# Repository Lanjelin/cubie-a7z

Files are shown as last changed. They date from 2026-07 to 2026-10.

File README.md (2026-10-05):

# Cubie A7Z setup notes

This repository is a working notebook for a Radxa Cubie A7Z running Armbian. It collects the bits that made the board useful: first-boot configuration, Wi-Fi fallback setup, fan control, e-paper display experiments, a status display script, and printable enclosure files.

It is intentionally practical rather than polished. Some directories are hardware bring-up notes, some are deployable scripts, and some are snapshots of a known-good local environment.

<p align="center">
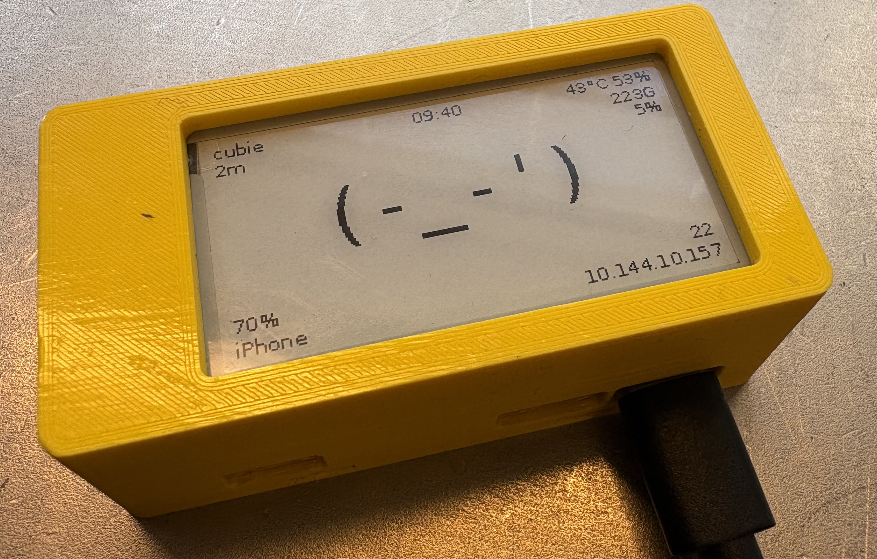
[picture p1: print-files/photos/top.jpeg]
Cubie A7Z enclosure top view
  
</p>

<p align="center">
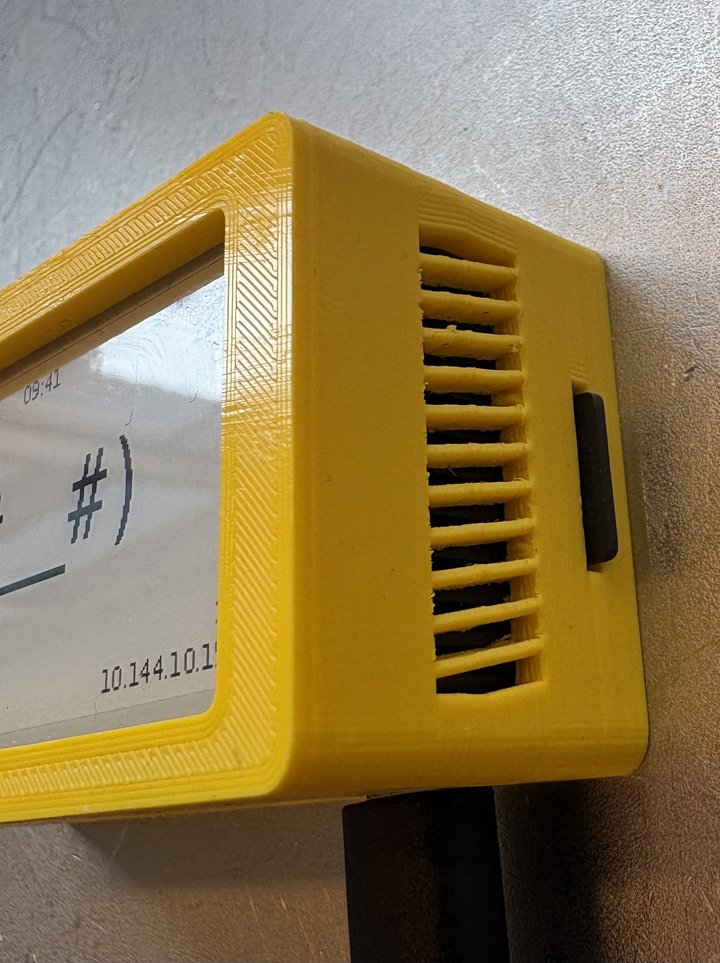
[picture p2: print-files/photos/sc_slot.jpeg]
Cubie A7Z enclosure SD card slot detail
  
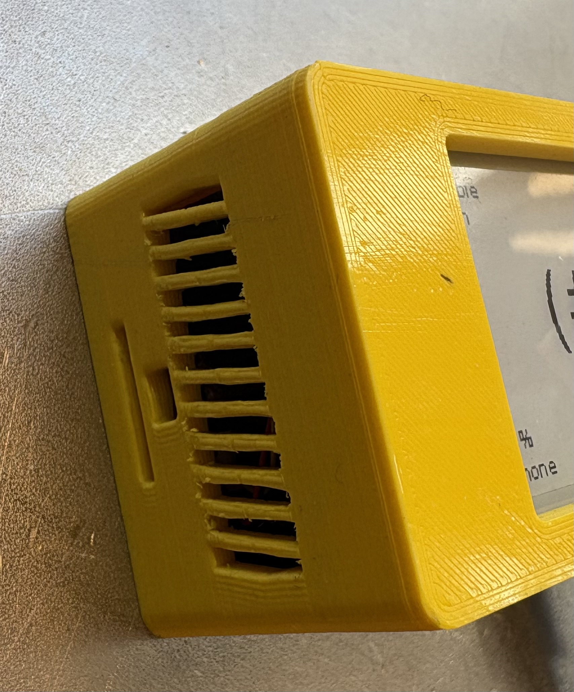
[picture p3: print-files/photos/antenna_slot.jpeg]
Cubie A7Z enclosure antenna slot detail
  
</p>

## Quick start order

This is the intended path through the repo when bringing up a fresh Cubie A7Z:

1. Flash an Armbian image for the Cubie A7Z.
2. Optionally prepare first boot with `armbian/.not_logged_in_yet.example`.
3. For the current Waveshare display, install the `cubie-header-io-power` overlay and verify `/dev/spidev1.0`; the current base DTB already enables SPI1.
4. Configure Wi-Fi and the fallback AP from `wifi/`.
5. Install `fan/` if using the vendor stock cooling/fan.
6. Test the e-paper status display with `screen-time/screen-time.py --once`.
7. Install `screen-time/screen-time.service` for boot startup.
8. Print or modify the enclosure from `print-files/`.

## Printable enclosure

The Cubie A7Z enclosure files live in [`print-files/`](print-files/). That folder includes editable CAD, STEP export, print-ready 3MF files, CAD screenshots, and photos of the printed result. The enclosure covers the stock vendor cooling/fan setup and includes ventilation holes plus cutouts for the camera, antenna, SD card, HDMI, and USB.

## Repository map

| Path | What it contains |
| --- | --- |
| `armbian/` | Armbian-specific setup notes. `armbian/.not_logged_in_yet.example` is a first-boot autoconfig template copied from the Armbian documentation. |
| `fan/` | A simple PWM fan daemon for the Cubie A7Z plus a systemd unit. The daemon reads thermal zones, ignores `skin_zone`, and writes `/sys/class/hwmon/hwmon1/pwm1` using a small temperature curve. |
| `wifi/` | NetworkManager/netplan notes for normal Wi-Fi plus a fallback access point. The timer/service waits after boot and starts the `cubie-ap` connection if `wlan0` never gets an IPv4 address or active Wi-Fi client connection. |
| `inky-fix/` | The older Pimoroni Inky pHAT bring-up path. Includes the Cubie A7Z patch, SPI1 overlay source/compiled DTBO, and minimal examples for the SSD1608 pHAT driver. |
| `waveshare-2in13-v4/` | Waveshare 2.13 inch e-Paper HAT+ V4 bring-up. Includes a trimmed vendored `waveshare_epd/` driver copy, examples, and the `cubie-header-io-power.dts` source. |
| `screen-time/` | The current Waveshare-based status display project. It bundles the patched Waveshare driver, header power overlay source, minimal Python requirements, and `screen-time.py`, which renders a landscape status screen and uses partial refreshes with periodic full refreshes. |
| `print-files/` | Printable Cubie A7Z enclosure files: editable CAD, STEP export, print-ready 3MF files, screenshots, photos, and feature notes in `print-files/README.md`. |

## Armbian notes

The board is running Armbian.

- General Armbian documentation: <https://docs.armbian.com/>
- First-boot autoconfig docs: <https://docs.armbian.com/User-Guide_Autoconfig/>
- Local template: [`armbian/.not_logged_in_yet.example`](armbian/.not_logged_in_yet.example)
- Radxa Cubie A7Z Armbian images: <https://github.com/NickAlilovic/build/releases>
- Armbian forum thread for Radxa Cubie A7 / A7Z / Allwinner A733: <https://forum.armbian.com/topic/56130-radxa-cubie-a7aa7z-allwinner-a733/>

Typical flow for first boot:

1. Flash an Armbian image.
2. Mount the flashed image or boot media.
3. Copy `armbian/.not_logged_in_yet.example` to `/root/.not_logged_in_yet` on that mounted filesystem.
4. Replace every placeholder value before booting. Armbian stores these values in plaintext, including Wi-Fi and user/root passwords.
5. Boot the Cubie A7Z and let Armbian consume the file during first boot.

## Current Waveshare header power overlay

The current kernel base DTB already enables SPI1 with native `PD10`–`PD13` pinctrl and one `spidev@0`, exposing `/dev/spidev1.0`. Do not load the old manual-CS SPI overlay for the current Waveshare setup. The necessary recovery is to keep the header I/O-bank power switch enabled.

The confirmed black/white Waveshare 2.13inch V4 HAT mapping is:

| Signal | Header pin | GPIO/controller |
| --- | --- | --- |
| Reset | 11 | `PB1`, `gpiochip0` offset `33` |
| BUSY | 18 | `PJ25`, `gpiochip0` offset `313` |
| DC | 22 | `PL5`, `gpiochip1` offset `5` |
| CS | 24 | `PD10`, native SPI1 chip select owned by the kernel |

Offsets are local to each gpiochip, not BCM numbers. The backend sets `CS_PIN=None`, leaving GPIO CS writes as no-ops; never request `PD10` with gpiod. SPI uses bus `1`, device `0`, mode `0`, `500000` Hz and `no_cs=False`.

`screen-time/cubie-header-io-power.dts` (also preserved in `waveshare-2in13-v4/`) adds only `regulator-boot-on` and `regulator-always-on` to `&reg_dc1sw1`. This enables `VCC33-LCD`/`SWOUT1` power for the PD (SPI1) and PJ (BUSY) banks without changing pinctrl or disabling Wi-Fi. The deployed application in `/opt/screen-time` does not need an overlay source or compiled DTBO at runtime; keep the checked-in source for rebuilding the boot overlay.

From the repository root:

```bash
dtc -@ -I dts -O dtb -o screen-time/cubie-header-io-power.dtbo screen-time/cubie-header-io-power.dts
sudo install -d /boot/overlay-user
sudo install -m 0644 screen-time/cubie-header-io-power.dtbo /boot/overlay-user/cubie-header-io-power.dtbo
sudo nano /boot/armbianEnv.txt
```

Edit the existing `user_overlays` line, removing the obsolete `sun60iw2p1-spi1-spidev-manual-cs` token and adding `cubie-header-io-power`. Preserve any unrelated tokens. With no unrelated overlays:

```ini
user_overlays=cubie-header-io-power
```

Keep Wi-Fi enabled; no Wi-Fi disable overlay is needed. Reboot to apply the boot-time power change:

```bash
sudo reboot
```

After reconnecting, verify the SPI node and follow `screen-time/README.md` for dependencies, a `screen-time.py --once` run, and service installation. A present SPI node alone does not prove that the header banks are powered.

### Apt-upgrade regression and confirmed recovery

The upgraded base DTB omitted the original Radxa board DTS's `regulator-boot-on` for `dc1sw1`. SPI1 remained enabled, and GPIO/pinctrl source was unchanged, but `dc1sw1` was disabled while its parent `DCDC1` still supplied 3.3 V. The resulting unpowered `VCC33-LCD` header banks caused the display failure.

With `cubie-header-io-power` and native CS, the recovery diagnostic showed BUSY rising and a full refresh of `2.283 s`; visible panel updates were confirmed. The deployed status application also completed full and partial refreshes, with a partial-refresh BUSY wait of about `0.60 s`. The installed recovery uses `user_overlays=cubie-header-io-power` and preserves Wi-Fi.

References: [Radxa A7Z schematic v1.11, pages 4 and 7](https://dl.radxa.com/cubie/a7z/docs/hw/radxa_cubie_a7z_schematic_v1.11.pdf) and [original Radxa board DTS](https://github.com/radxa/allwinner-device/blob/device-a733-v1.4.8/configs/cubie_a7z/linux-6.6/board.dts).

### Historical Inky overlay path

`inky-fix/` retains its old `spi1-spidev-manual-cs.dts` and `sun60iw2p1-spi1-spidev-manual-cs.dtbo` for the older Pimoroni bring-up path. Those assets are historical and are not the active Waveshare overlay; do not load them alongside the current native-CS base DTB. They have intentionally been left intact.

## Display work

There are three display-related folders because the setup moved from Inky experiments to the current Waveshare status display.

### `inky-fix/`

Captures the Pimoroni Inky pHAT path. `inky.auto.auto()` did not work on this board because the EEPROM was not visible on the accessible I2C buses, so the working path used the manual SSD1608 pHAT class with Cubie-specific pins.

### `waveshare-2in13-v4/`

Captures the Waveshare 2.13 inch e-Paper HAT+ V4 bring-up. It keeps a local `waveshare_epd/` copy so Cubie pin and SPI fixes can be made without patching a global install. The full upstream Waveshare repository is <https://github.com/waveshareteam/e-Paper>.

### `screen-time/`

The status display application built on the Waveshare V4 setup. It defaults `EPD_PLATFORM=cubie`, imports its bundled `waveshare_epd` driver, renders through Pillow, and supports:

- one-shot test mode with `python3 screen-time.py --once`
- normal loop mode with `python3 screen-time.py`
- custom refresh interval with `python3 screen-time.py --interval 15`

## Wi-Fi fallback access point

`wifi/` contains notes and unit files for making the board recoverable when normal Wi-Fi does not connect.

- `etc_netplan_30-wifis-dhcp.yaml.example` is a netplan Wi-Fi config snapshot.
- `nmcli_network_priority_ap` records NetworkManager commands for connection priorities and the fallback AP.
- `wifi-fallback-ap.sh` waits for normal Wi-Fi, then brings up `cubie-ap` if no IPv4 address or active Wi-Fi client connection exists.
- `wifi-fallback-ap.service` and `wifi-fallback-ap.timer` run that check after boot.

## Fan daemon

`fan/cubie-fand` is a small Python daemon intended to be installed as `/usr/local/sbin/cubie-fand` and run with `fan/cubie-fand.service`.

It sets manual PWM mode, starts at a minimum PWM, samples thermal zones every five seconds, and raises/lowers the fan using hysteresis to avoid rapid speed changes.

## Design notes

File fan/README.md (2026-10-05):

# Cubie A7Z fan daemon

This directory contains a small PWM fan controller for the Cubie A7Z stock cooling/fan setup.

`cubie-fand` reads thermal zones from `/sys/class/thermal`, ignores `skin_zone`, and writes PWM values to the hwmon device whose `name` is `pwmfan`. The `hwmonN` number is discovered at startup, not hard-coded. It uses a small temperature curve plus hysteresis so the fan does not constantly bounce between speeds.

## Files

| File | Purpose |
| --- | --- |
| `cubie-fand` | Python fan control daemon. |
| `cubie-fand.service` | systemd service unit. |
| `cubie-pwm-fan.dts` / `.dtbo` | Restore the fan device and PWM1 channel 9 routing to PJ27 after the kernel upgrade. |

## Kernel-upgrade recovery

The upgraded base DTB omits the original `pwm-fan` device and routes PWM1 channel 9 to PK5 instead of the fan connector's PJ27. The kernel includes `pwm-fan.ko`, but without the device node there is no fan hwmon interface: the old daemon crashes at startup and the status display shows `--%`.

`cubie-pwm-fan.dts` restores PJ27 active/sleep pinctrl and a `pwm-fan` device using PWM1 channel 9 at a 25,000 ns period (40 kHz). It also keeps `reg_dc1sw1` enabled for the PJ I/O bank, independently of the e-paper overlay. The fan's J6 power pin is fixed 5 V, not `dc1sw1`; that regulator powers the control pin's I/O bank.

The overlay deliberately adds no thermal cooling maps: `cubie-fand` remains the sole temperature-curve controller. The display percentage is PWM duty cycle, not measured RPM; the connector has no tachometer input. The daemon keeps the existing `pwm1_enable=1` behavior and reports enable/write failures instead of silently ignoring them.

References: [original Radxa board DTS](https://github.com/radxa/allwinner-device/blob/device-a733-v1.4.8/configs/cubie_a7z/linux-6.6/board.dts) and [A7Z schematic V1.11, pages 7 and 16](https://dl.radxa.com/cubie/a7z/docs/hw/radxa_cubie_a7z_schematic_v1.11.pdf).

## Install

Run from this checkout's `fan/` directory. Compilation needs no elevation; installation, boot configuration, and reboot require `sudo`.

```bash
dtc -@ -I dts -O dtb -o cubie-pwm-fan.dtbo cubie-pwm-fan.dts
sudo systemctl stop cubie-fand.service
sudo install -d /boot/overlay-user
sudo install -m 0644 cubie-pwm-fan.dtbo /boot/overlay-user/cubie-pwm-fan.dtbo
sudo install -m 0755 cubie-fand /usr/local/sbin/cubie-fand
sudo install -m 0644 cubie-fand.service /etc/systemd/system/cubie-fand.service
sudo systemctl daemon-reload
sudo systemctl enable cubie-fand.service
sudo nano /boot/armbianEnv.txt
```

Append `cubie-pwm-fan` to the existing `user_overlays` line, preserving unrelated tokens. With the existing e-paper power overlay and no other overlays:

```ini
user_overlays=cubie-header-io-power cubie-pwm-fan
```

Keep the e-paper overlay and Wi-Fi configuration unchanged. Do not start the daemon until the new device tree is active:

```bash
sudo reboot
```

After reconnecting, inspect the fan interface and service:

```bash
for h in /sys/class/hwmon/hwmon*; do
    [ "$(cat "$h/name" 2>/dev/null)" = pwmfan ] || continue
    printf '%s: PWM=' "$h"
    cat "$h/pwm1"
    printf 'PWM enable mode='
    cat "$h/pwm1_enable"
done
systemctl status cubie-fand.service --no-pager
journalctl -u cubie-fand.service -b -n 20 --no-pager
```

Expected: one `pwmfan` device, a running daemon, and PWM `128` (about 50%) at temperatures below 45°C. Above that, the curve below applies. Check that the fan physically spins and the status display replaces `--%` with a numeric value.

If the fan interface is absent, inspect kernel logs for PWM probe errors; do not export or directly drive the raw PWM channel while debugging. To roll back, stop/disable `cubie-fand.service`, remove only the `cubie-pwm-fan` token from `user_overlays`, and reboot.

Verification before installation: the compiled overlay applied to the installed base DTB alongside `cubie-header-io-power`; PWM resolves to channel 9 at 40 kHz and both pinctrl states resolve to PJ27. A filesystem-backed daemon smoke run discovered `hwmon7`, ignored an unrelated PWM device, and produced duty transitions `136 → 136 → 128` at `46 → 41 → 40°C`. Physical fan operation and the display readout require post-reboot verification.

## Fan curve

The current curve starts at `MIN_PWM = 128` and increases through these temperature/PWM points:

| Temperature | PWM |
| --- | --- |
| 45°C | 136 |
| 50°C | 144 |
| 55°C | 152 |
| 60°C | 160 |
| 70°C | 192 |
| 80°C | 224 |
| 88°C | 255 |

Decrease hysteresis is `5°C`.

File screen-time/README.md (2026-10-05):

# Screen Time for Waveshare 2.13inch e-Paper HAT+ V4 on Cubie A7Z

This directory is self-contained for the Waveshare version of `screen-time.py`.

It includes:

- `screen-time.py`: the status display script, updated from Inky to Waveshare V4
- `waveshare_epd/`: vendored Waveshare Python driver with the working Cubie pin mapping
- `requirements.txt`: minimal Python dependencies for the current Waveshare status display
- `cubie-header-io-power.dts`: source for the header I/O-bank power overlay; the deployed application does not need a source/DTBO copy in `/opt/screen-time` at runtime

## Working Cubie wiring for the Waveshare HAT

- `PIN_22` DC = `gpiochip1` offset `5` (`PL5`)
- `PIN_11` reset = `gpiochip0` offset `33` (`PB1`)
- `PIN_18` busy = `gpiochip0` offset `313` (`PJ25`)
- `PIN_24` CS = native SPI1 chip select (`PD10`), owned by the kernel; never request it with gpiod
- `/dev/spidev1.0`: SPI bus `1`, device `0`, mode `0`, `500000` Hz, `no_cs=False`

The Cubie backend uses `CS_PIN=None`, so Waveshare's GPIO chip-select writes are no-ops and the SPI controller drives CS. These are gpiochip-local offsets, not BCM numbers. Keep Wi-Fi enabled; no Wi-Fi disable overlay is needed.

## Boot-time header power overlay

The current kernel base DTB already enables SPI1 with native `PD10`–`PD13` pinctrl and one `spidev@0` device. Do not load the old manual-CS SPI overlay: it conflicts with this native-CS configuration. `/dev/spidev1.0` existing alone does not prove that the header I/O banks are powered.

`cubie-header-io-power.dts` adds only `regulator-boot-on` and `regulator-always-on` to `&reg_dc1sw1`. This switch supplies `VCC33-LCD`/`SWOUT1`, powering the PD (SPI1) and PJ (BUSY) banks; it does not change SPI pinctrl or disable Wi-Fi.

Compile and install it from this `screen-time/` directory on Armbian:

```bash
dtc -@ -I dts -O dtb -o cubie-header-io-power.dtbo cubie-header-io-power.dts
sudo install -d /boot/overlay-user
sudo install -m 0644 cubie-header-io-power.dtbo /boot/overlay-user/cubie-header-io-power.dtbo
sudo nano /boot/armbianEnv.txt
```

In the existing `user_overlays` line, remove the obsolete `sun60iw2p1-spi1-spidev-manual-cs` token and add `cubie-header-io-power`, preserving every unrelated overlay token. With no unrelated overlays, the line is:

```ini
user_overlays=cubie-header-io-power
```

Do not add a Wi-Fi disable overlay. Reboot for the boot-time power change to take effect, then check the SPI device and run the one-shot display test below:

```bash
sudo reboot
```

After reconnecting:

```bash
ls /dev/spidev1.0
```

### Apt-upgrade regression and recovery

After the upgrade, SPI1 was still present but `dc1sw1` was disabled while its parent `DCDC1` remained at 3.3 V. The upgraded base DTB omitted the original board DTS's `regulator-boot-on`; GPIO/pinctrl source was unchanged. Unpowered `VCC33-LCD` header banks, not different GPIO pins or a different display controller, caused the missing updates.

With this power overlay and native CS, the recovery diagnostic produced a BUSY rise and a full refresh in `2.283 s`; visible panel updates were confirmed. The deployed status application also completed full and partial refreshes, with a partial-refresh BUSY wait of about `0.60 s`. The installed recovery uses `user_overlays=cubie-header-io-power` and leaves Wi-Fi enabled.

References: [Radxa A7Z schematic v1.11, pages 4 and 7](https://dl.radxa.com/cubie/a7z/docs/hw/radxa_cubie_a7z_schematic_v1.11.pdf) and [original Radxa board DTS](https://github.com/radxa/allwinner-device/blob/device-a733-v1.4.8/configs/cubie_a7z/linux-6.6/board.dts).

## Running

The script adds its own directory to `sys.path` and defaults `EPD_PLATFORM=cubie`, so it can use the bundled driver directly.

Run the following commands from this `screen-time/` directory in your checkout.

Install the minimal Python dependencies:

```bash
python3 -m pip install -r requirements.txt
```

One-shot test:

```bash
python3 screen-time.py --once
```

Normal loop:

```bash
python3 screen-time.py
```

Custom refresh interval:

```bash
python3 screen-time.py --interval 15
```

## Install as a boot service

`screen-time.service` runs the display as root because the script needs direct SPI/GPIO access. The unit assumes the deployed files live in `/opt/screen-time`.

From this directory:

```bash
sudo install -d /opt/screen-time
sudo cp -a screen-time.py waveshare_epd README.md requirements.txt /opt/screen-time/
sudo install -m 0644 screen-time.service /etc/systemd/system/screen-time.service
```

Optional local overrides:

```bash
sudo install -m 0644 screen-time.env.example /etc/default/screen-time
sudo nano /etc/default/screen-time
```

Available overrides:

- `SCREEN_TIME_INTERVAL=10`: seconds between update checks.
- `SCREEN_TIME_TUNNEL_REMOTE=`: optional `host:port` endpoint for the ▲/▼ tunnel indicator. Leave blank to skip that check completely.
- `SCREEN_TIME_HIDDEN_PORTS=111,5355`: comma-separated listening ports hidden from the port list.

Enable and start the service:

```bash
sudo systemctl daemon-reload
sudo systemctl enable --now screen-time.service
systemctl status screen-time.service
```

Logs:

```bash
journalctl -u screen-time.service -f
```

Before enabling the service, verify the boot overlay and Python dependencies manually:

```bash
ls /dev/spidev1.0
python3 screen-time.py --once
```

If your Python dependencies live in a virtualenv instead of system Python, edit `/etc/systemd/system/screen-time.service` and change `/usr/bin/python3` in `ExecStart` to the venv interpreter path.

## Notes

- This version now uses a full refresh to establish the base image, then uses Waveshare partial refresh for subsequent updates.
- After a number of partial refreshes, it forces a full refresh again to limit ghosting.
- The current implementation still sends the full framebuffer; it does not yet do true rectangle-only hardware partial window updates.
- The script renders onto a landscape canvas and feeds it through the Waveshare V4 driver.
- The vendored driver already contains the working Cubie pin mapping, so no separate patch file is needed.

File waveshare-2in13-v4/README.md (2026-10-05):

# Waveshare 2.13inch e-Paper HAT+ V4

This workspace is for the black/white Waveshare 2.13inch e-Paper HAT+ V4 with partial refresh support.

## Confirmed Cubie A7Z setup

The current kernel base DTB already enables SPI1, with native `PD10`–`PD13` pinctrl and one `spidev@0` device. No SPI-enabling/manual-CS overlay is needed. The required overlay is `cubie-header-io-power`, which keeps the header I/O-bank supply enabled. Wi-Fi stays enabled.

| HAT signal | Header pin | GPIO/controller |
| --- | --- | --- |
| Reset | 11 | `PB1`, `gpiochip0` offset `33` |
| BUSY | 18 | `PJ25`, `gpiochip0` offset `313` |
| DC | 22 | `PL5`, `gpiochip1` offset `5` |
| CS | 24 | `PD10`, native SPI1 chip select owned by the kernel |

These are gpiochip-local offsets, not BCM numbers. The Cubie backend uses `/dev/spidev1.0` (bus `1`, device `0`), SPI mode `0`, `500000` Hz and `no_cs=False`. It sets `CS_PIN=None`; Waveshare's GPIO CS toggles are no-ops. Never request `PD10` with gpiod.

The older Inky driver patch and its manual-CS SPI overlay are not the current Waveshare setup.

## Vendored driver

A minimal copy of the Waveshare Python driver lives in:

- `waveshare_epd/`

That directory contains only the files needed for the 2.13inch V4 board:

- `__init__.py`
- `epd2in13_V4.py`
- `epdconfig.py`

Use this copy when you want to patch the driver for Cubie instead of editing the downloaded repo.

## How to include `waveshare_epd`

Keep `waveshare_epd/` inside your project and add the project root to `sys.path` before the first import:

```python
import sys
from pathlib import Path

sys.path.insert(0, str(Path(__file__).resolve().parents[1]))

from waveshare_epd import epd2in13_V4
```

If you prefer environment setup instead of modifying the script, export these variables from this `waveshare-2in13-v4/` directory:

```bash
export PYTHONPATH="$PWD"
export EPD_PLATFORM=cubie
```

`EPD_PLATFORM=cubie` forces the patched Cubie backend in `epdconfig.py`.

- `cubie-header-io-power.dts`: proven two-property header power overlay source
- Python dependencies are intentionally not frozen here; use `../screen-time/requirements.txt` for the current Waveshare status display setup
- `examples/hello_world_v4_fast.py`: V4 fast-refresh example using the bundled Cubie backend

## Boot-time header power overlay

`VCC33-LCD`/`SWOUT1`, switched by `dc1sw1`, powers the PD (SPI1) and PJ (BUSY) header banks. The supplied overlay adds only `regulator-boot-on` and `regulator-always-on` to `&reg_dc1sw1`; it does not alter pinctrl or Wi-Fi.

From this directory, compile with symbol support and install on Armbian:

```bash
dtc -@ -I dts -O dtb -o cubie-header-io-power.dtbo cubie-header-io-power.dts
sudo install -d /boot/overlay-user
sudo install -m 0644 cubie-header-io-power.dtbo /boot/overlay-user/cubie-header-io-power.dtbo
sudo nano /boot/armbianEnv.txt
```

Edit the existing `user_overlays` line: remove the obsolete `sun60iw2p1-spi1-spidev-manual-cs` token, add `cubie-header-io-power`, and preserve all unrelated tokens. With no unrelated overlays:

```ini
user_overlays=cubie-header-io-power
```

Do not load the old manual-CS overlay or add a Wi-Fi disable overlay. Reboot to apply the power overlay:

```bash
sudo reboot
```

After reconnecting, check the device and run the V4 example from this directory:

```bash
ls /dev/spidev1.0
python3 examples/hello_world_v4_fast.py
```

The presence of `/dev/spidev1.0` alone is not proof that the header banks are powered or the panel updates. For the status display's full-refresh/partial-refresh workflow, see `../screen-time/README.md` and run `screen-time.py --once` before enabling its service.

### Apt-upgrade regression and recovery

The upgraded base DTB omitted the original Radxa board DTS's `regulator-boot-on` for `dc1sw1`. At runtime, this switch was disabled although its parent `DCDC1` supplied 3.3 V. SPI1 remained enabled and GPIO/pinctrl source was unchanged; the missing `VCC33-LCD` bank power caused the failure, not a changed display controller or GPIO mapping.

With `cubie-header-io-power` loaded and native CS, the recovery diagnostic showed BUSY rising and a full refresh lasting `2.283 s`; actual visible updates were confirmed. The deployed status application also completed full and partial refreshes, with a partial-refresh BUSY wait of about `0.60 s`. The installed boot configuration uses `user_overlays=cubie-header-io-power`, with Wi-Fi enabled.

References: [Radxa A7Z schematic v1.11, pages 4 and 7](https://dl.radxa.com/cubie/a7z/docs/hw/radxa_cubie_a7z_schematic_v1.11.pdf) and [original Radxa board DTS](https://github.com/radxa/allwinner-device/blob/device-a733-v1.4.8/configs/cubie_a7z/linux-6.6/board.dts).

The official Waveshare e-Paper repository is here:

- https://github.com/waveshareteam/e-Paper

## Notes

- The display itself is different from the Inky pHAT, so the previous `inky`-specific code should not be reused directly.
- The Armbian boot-time deployment mechanism is reusable, but the current Waveshare overlay fixes header power rather than enabling SPI1.
- The vendored `waveshare_epd/` directory is the local copy to modify for Cubie-specific fixes.

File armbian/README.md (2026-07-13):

# Armbian notes for Radxa Cubie A7Z

This directory contains Armbian-specific first-boot setup notes for the Cubie A7Z.

Useful upstream/community links:

- Armbian documentation: <https://docs.armbian.com/>
- Armbian first-boot autoconfig: <https://docs.armbian.com/User-Guide_Autoconfig/>
- Cubie A7Z Armbian images: <https://github.com/NickAlilovic/build/releases>
- Armbian forum thread for Radxa Cubie A7A/A7Z / Allwinner A733: <https://forum.armbian.com/topic/56130-radxa-cubie-a7aa7z-allwinner-a733/>

## First-boot autoconfig

`./.not_logged_in_yet.example` is a public template for Armbian's `/root/.not_logged_in_yet` first-boot config.

Typical flow:

1. Flash the Armbian image.
2. Mount the flashed image or boot media.
3. Copy `.not_logged_in_yet.example` to `/root/.not_logged_in_yet` on the mounted filesystem.
4. Replace all placeholder values.
5. Boot the Cubie A7Z and let Armbian consume the file during first boot.

Example:

```bash
cp .not_logged_in_yet.example /path/to/mounted/root/.not_logged_in_yet
```

The values in `/root/.not_logged_in_yet` are plaintext. Do not commit a filled-out copy.

## Provisioning hook

Armbian also supports `/root/provisioning.sh`, which runs once as root after the first successful login. Use that for final local setup such as package installs, hostname changes, or service enablement.

See the upstream first-boot documentation for the current directive list and provisioning behavior: <https://docs.armbian.com/User-Guide_Autoconfig/>

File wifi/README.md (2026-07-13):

# Cubie A7Z Wi-Fi fallback AP

This directory captures the Wi-Fi setup used to keep the Cubie A7Z reachable when normal client Wi-Fi does not come up.

The idea is simple: configure the usual Wi-Fi networks with netplan/NetworkManager, define a disabled fallback access point named `cubie-ap`, then let a systemd timer run a small check after boot. If `wlan0` has no IPv4 address and NetworkManager has no active Wi-Fi client connection, the script starts `cubie-ap`.

## Files

| File | Purpose |
| --- | --- |
| `etc_netplan_30-wifis-dhcp.yaml.example` | Example netplan Wi-Fi config with placeholder SSIDs/passwords. |
| `nmcli_network_priority_ap.example` | Example NetworkManager commands for client priorities and the fallback AP. |
| `wifi-fallback-ap.sh` | Boot-time check that starts `cubie-ap` only when client Wi-Fi failed. |
| `wifi-fallback-ap.service` | oneshot systemd service for the check. |
| `wifi-fallback-ap.timer` | Runs the service after boot. |

The local non-example files are ignored by `.gitignore` because they normally contain real Wi-Fi names and PSKs:

- `etc_netplan_30-wifis-dhcp.yaml`
- `nmcli_network_priority_ap`

## Configure Wi-Fi

Use the examples as templates, then replace all placeholder values locally.

```bash
cp etc_netplan_30-wifis-dhcp.yaml.example etc_netplan_30-wifis-dhcp.yaml
cp nmcli_network_priority_ap.example nmcli_network_priority_ap
```

Install the netplan file if you use this netplan layout:

```bash
sudo install -m 0600 etc_netplan_30-wifis-dhcp.yaml /etc/netplan/30-wifis-dhcp.yaml
sudo netplan apply
```

Run the edited NetworkManager commands to set client priorities and create the fallback AP:

```bash
sh nmcli_network_priority_ap
```

## Install the fallback service

```bash
sudo install -m 0755 wifi-fallback-ap.sh /usr/local/bin/wifi-fallback-ap.sh
sudo install -m 0644 wifi-fallback-ap.service /etc/systemd/system/wifi-fallback-ap.service
sudo install -m 0644 wifi-fallback-ap.timer /etc/systemd/system/wifi-fallback-ap.timer
sudo systemctl daemon-reload
sudo systemctl enable --now wifi-fallback-ap.timer
```

Check timer state and logs:

```bash
systemctl status wifi-fallback-ap.timer
journalctl -u wifi-fallback-ap.service
```

## Manual test

After configuring `cubie-ap`, you can run the check manually:

```bash
sudo /usr/local/bin/wifi-fallback-ap.sh
```

If normal Wi-Fi is already connected, it should exit without changing anything. If no client connection is active, it should bring up `cubie-ap`.

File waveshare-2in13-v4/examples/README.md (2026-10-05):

# Examples

## Waveshare 2.13-inch BW V4 on Cubie A7Z

`hello_world_v4_fast.py` imports the bundled `waveshare_epd` driver and Cubie
backend. It performs fast initialization, clears to white, draws a text image,
uses fast refresh, and puts the panel to sleep.

```sh
EPD_PLATFORM=cubie python3 examples/hello_world_v4_fast.py
```

Run from the parent `waveshare-2in13-v4` directory with its dependencies
installed and no other process using the display.

The backend uses RST on header 11 (`gpiochip0` offset 33), DC on header 22
(`gpiochip1` offset 5), and active-high BUSY on header 18 (`gpiochip0` offset
313). SPI is `/dev/spidev1.0`, mode 0, 500 kHz; header 24 / PD10 is native SPI
chip select, not a userspace GPIO.

The confirmed setup requires the `cubie-header-io-power` overlay to keep DC1SW1
enabled for the PD/PJ banks. Do not load the old manual-CS overlay. See the
parent README for setup details.

The obsolete GPIO/manual-CS and SPI-mode sweep experiments have been removed.
Printed completion is not proof of a visible panel update; inspect the display.

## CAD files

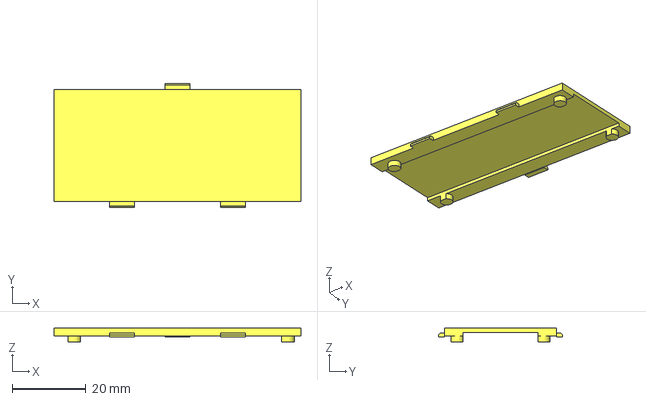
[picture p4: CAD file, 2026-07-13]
print-files/cubie-lid.3mf
67.0 x 33.8 x 3.80 mm

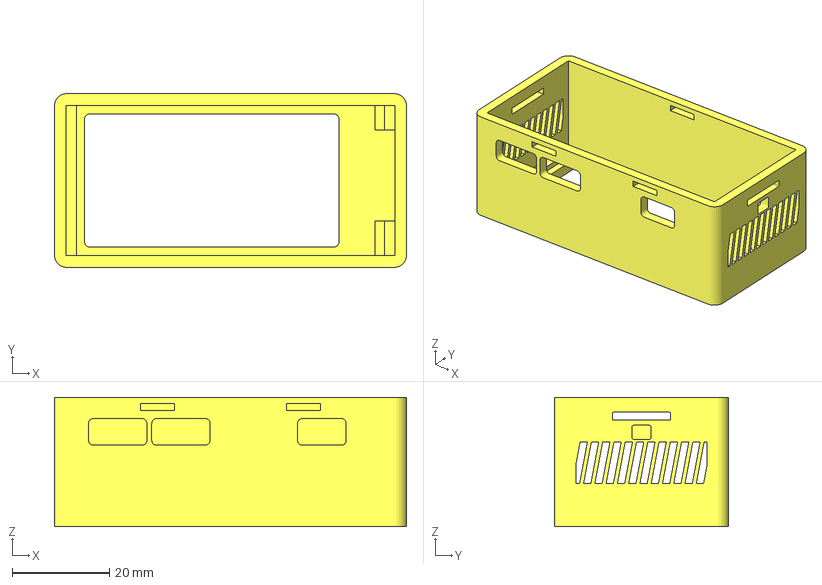
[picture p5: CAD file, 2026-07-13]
print-files/cubie-top.3mf
72.4 x 35.8 x 26.6 mm

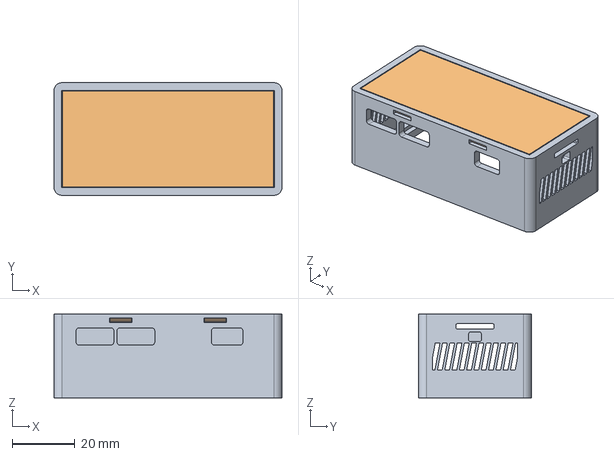
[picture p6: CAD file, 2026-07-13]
print-files/cubiea7z.step
72.4 x 35.8 x 26.6 mm

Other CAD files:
print-files/cubiea7z.f3d

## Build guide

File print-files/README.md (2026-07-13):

# Cubie A7Z enclosure print files

This directory contains the CAD source, exchange model, print-ready 3MF files, screenshots, and real photos for the Cubie A7Z enclosure.

<p align="center">
  Printed Cubie A7Z enclosure top view
</p>

<p align="center">
  Printed enclosure SD card slot detail
  Printed enclosure antenna slot detail
</p>

## Files

| File | Purpose |
| --- | --- |
| `cubiea7z.f3d` | Fusion 360 source file for editing the enclosure. |
| `cubiea7z.step` | Neutral CAD exchange file for inspection, remixing, or importing into other CAD tools. |
| `cubie-top.3mf` | Print-ready 3MF for the top/main enclosure body. |
| `cubie-lid.3mf` | Print-ready 3MF for the lid. |
| `screenshots/` | CAD/render screenshots showing the enclosure shape and cutouts. |
| `photos/` | Photos of the printed enclosure details. |

## Online model viewing

For a quick browser-based look at the model, open [`cubiea7z.step`](cubiea7z.step) with an online STEP viewer such as [3DViewer.net](https://3dviewer.net/).

## Design features

- Ventilation holes aligned for the Cubie A7Z with the vendor stock cooling/fan installed.
- Camera cutout.
- Antenna cutout.
- SD card cutout.
- HDMI and USB cutouts.

## CAD screenshots

<p align="center">
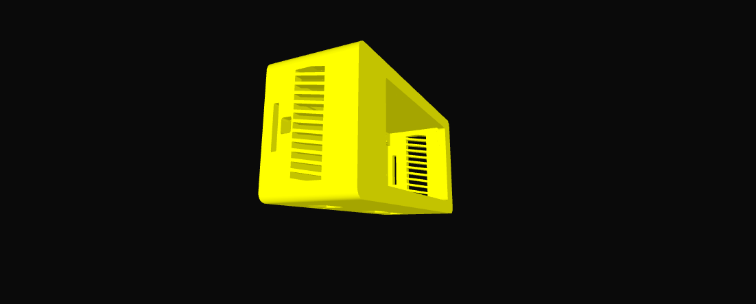
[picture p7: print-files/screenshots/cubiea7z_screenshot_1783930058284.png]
Cubie A7Z enclosure CAD screenshot showing ventilation and side cutouts
  
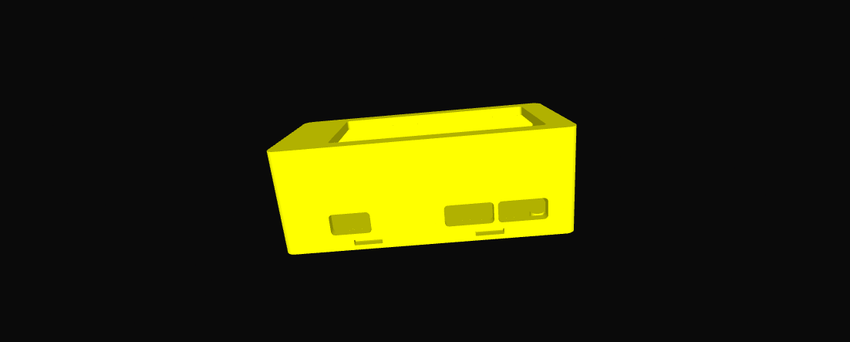
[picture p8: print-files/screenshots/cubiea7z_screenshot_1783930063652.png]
Cubie A7Z enclosure CAD screenshot showing HDMI and USB cutouts
  
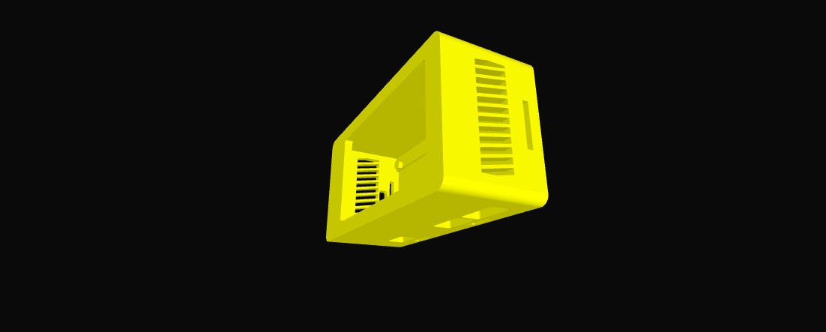
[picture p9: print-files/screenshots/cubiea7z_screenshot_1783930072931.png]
Cubie A7Z enclosure CAD screenshot showing fan ventilation and board opening
  
</p>

## Notes

The compiled print files are kept alongside the editable CAD files so the known-good print artifacts are available without needing to rebuild/export from Fusion first.

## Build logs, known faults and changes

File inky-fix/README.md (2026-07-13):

# Inky Cubie A7Z Fix

This folder captures the working setup for the Cubie A7Z with the 2.13" Inky pHAT (SSD1608).

## What this is for

- `inky.auto.auto()` does not work on this board because the EEPROM is not visible on any of the accessible I2C buses.
- The working display path is the manual SSD1608 pHAT driver.
- The Cubie wiring uses:
  - `PIN_11` busy = `gpiochip0` line `33`
  - `PIN_24` CS = `gpiochip0` line `106`
  - `PIN_13` reset = `gpiochip1` line `6`
  - `PIN_15` DC = `gpiochip1` line `7`
  - `spidev1.0`

## Files

- `inky-cubie-a7z.patch`: patch for the installed `inky` library
- Python dependencies are intentionally not frozen here; install the Pimoroni `inky` package version that matches your target environment before applying the patch.
- `spi1-spidev-manual-cs.dts`: source for the custom overlay
- `sun60iw2p1-spi1-spidev-manual-cs.dtbo`: compiled boot-time overlay required for `/dev/spidev1.0` and the Cubie GPIO mapping
- `examples/hello_world_3x.py`: minimal visible test

## Boot-time overlay

This setup assumes your custom device-tree overlay is loaded at boot. The source is `spi1-spidev-manual-cs.dts` and the compiled artifact is `sun60iw2p1-spi1-spidev-manual-cs.dtbo`.

On Armbian, install the compiled DTBO at:

- `/boot/overlay-user/sun60iw2p1-spi1-spidev-manual-cs.dtbo`

Then edit `/boot/armbianEnv.txt` and add:

```ini
user_overlays=sun60iw2p1-spi1-spidev-manual-cs
```

After applying the changes in `/boot`, reboot the board for the overlay to take effect. You can verify it loaded with:

```bash
ls /dev/spidev1.0
```

That overlay is responsible for exposing:

- `/dev/spidev1.0`
- `gpiochip0` line `33` for `PIN_11` busy
- `gpiochip0` line `106` for `PIN_24` CS
- `gpiochip1` line `6` for `PIN_13` reset
- `gpiochip1` line `7` for `PIN_15` DC

The patch and the example only work correctly when that overlay is already active at boot.

## How to include this in a project

Recommended flow:

1. Create or activate the project virtualenv.
2. Build and install the boot-time overlay: copy `sun60iw2p1-spi1-spidev-manual-cs.dtbo` to `/boot/overlay-user/` and add `user_overlays=sun60iw2p1-spi1-spidev-manual-cs` to `/boot/armbianEnv.txt`.
3. Install the Pimoroni `inky` package and its normal dependencies for your target environment.
4. Apply `inky-cubie-a7z.patch` to the installed `inky` package.
5. Import the SSD1608 pHAT driver directly in your code:

```python
from inky.phat import InkyPHAT_SSD1608
```

6. Instantiate it manually with the Cubie pin mapping:

```python
inky = InkyPHAT_SSD1608("black")
inky.cs_pin = "CUBIE_HW_CS"
inky.dc_pin = "PIN_15"
inky.reset_pin = "PIN_13"
inky.busy_pin = "PIN_11"
```

7. Build your image with PIL and call `set_image()` and `show()`.

## Notes

- Do not rely on `auto()` on this board unless the EEPROM becomes visible on a usable I2C bus.
- The working display path is the SSD1608 pHAT class, not the generic base driver.
- The panel on this setup renders with an inverted-looking palette relative to the PIL buffer values. The example uses the known-good polarity.

## Applying the patch

From the `site-packages` directory of the virtualenv:

```bash
cd ~/.venvs/inky/lib/python3.13/site-packages
patch -p1 < /home/las/inky-fix/inky-cubie-a7z.patch
```

If you vendor `inky` inside a project, apply the same patch relative to that vendored copy.

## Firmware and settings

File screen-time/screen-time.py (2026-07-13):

#!/usr/bin/env python3

import argparse
import os
import random
import shutil
import subprocess
import sys
from pathlib import Path
from time import sleep

BASE_DIR = Path(__file__).resolve().parent
sys.path.insert(0, str(BASE_DIR))
os.environ.setdefault('EPD_PLATFORM', 'cubie')

from PIL import Image, ImageDraw, ImageFont
from waveshare_epd import epd2in13_V4

# started by /lib/systemd/system/time.service
# keep this script together with the bundled waveshare_epd/ directory

# Local policy/config that is likely to vary between machines.
HIDDEN_PORTS = {
    port for port
    in os.environ.get('SCREEN_TIME_HIDDEN_PORTS', '111,5355').replace(',', ' ').split()
    if port
}
TUNNEL_REMOTE = os.environ.get('SCREEN_TIME_TUNNEL_REMOTE', '').strip()


class Screen:
    @staticmethod
    def _text_bbox(font, text):
        return font.getbbox(text)

    @classmethod
    def _text_size(cls, font, text):
        left, top, right, bottom = cls._text_bbox(font, text)
        return right - left, bottom - top

    @staticmethod
    def _run(command):
        return subprocess.getoutput(command).strip()

    def __init__(self):
        self.saved_time = '00:00'
        self.saved_ssid = 'Connecting...'
        self.saved_signal = '--%'
        self.saved_ip = ''
        self.saved_face = '(ᵔ◡◡ᵔ)'
        self.saved_temp = '--°C'
        self.saved_fan = '--%'
        self.saved_uptime = '--'
        self.saved_disk = '--'
        self.saved_ram = '--'
        self.ports = ''
        self.push_update = True
        self.partial_ready = False
        self.partial_updates = 0
        self.full_refresh_every = 25

        self.name = self._run('hostname') or 'cubie'

        self.epd = epd2in13_V4.EPD()
        self.canvas_width = self.epd.height
        self.canvas_height = self.epd.width
        self.margin_x = 2
        self.margin_y = 2

        self.font_small_path = '/usr/share/fonts/truetype/dejavu/DejaVuSans.ttf'
        self.font_face_path = '/usr/share/fonts/truetype/dejavu/DejaVuSansMono.ttf'
        try:
            self.font_small = ImageFont.truetype(self.font_small_path, 10)
            self.font_face = ImageFont.truetype(self.font_face_path, 40)
        except OSError:
            self.font_small = ImageFont.load_default()
            self.font_face = ImageFont.load_default()

        self.faces = [
            '( ⚆_⚆)', '(☉_☉ )', '( ◕‿◕)', '(◕‿◕ )', '(⇀‿‿↼)', '(≖‿‿≖)',
            '(◕‿‿◕)', '(-__-)', '(°▃▃°)', '(⌐■_■)', '(•‿‿•)', '(^‿‿^)',
            '(ᵔ◡◡ᵔ)', '(☼‿‿☼)', '(≖__≖)', '(✜‿‿✜)', '(ب__ب)', '(╥☁╥ )',
            "(-_-')", '(♥‿‿♥)', '(☓‿‿☓)', '(#__#)', '(1__0)', '(1__1)', '(0__1)'
        ]

        self.loc_top_left = (0, 0)
        self.loc_top_left_sub = (0, 0)
        self.loc_top_center = (0, 0)
        self.loc_top_right = (0, 0)
        self.loc_top_right_sub = (0, 0)
        self.loc_top_right_sub2 = (0, 0)
        self.loc_center = (0, 0)
        self.loc_bot_left = (0, 0)
        self.loc_bot_left_sub = (0, 0)
        self.loc_bot_right = (0, 0)
        self.loc_bot_right_sub = (0, 0)

    def _fit_text(self, text, font, max_width):
        if self._text_size(font, text)[0] <= max_width:
            return text
        if max_width <= self._text_size(font, '...')[0]:
            return ''
        trimmed = text
        while trimmed:
            candidate = trimmed + '...'
            if self._text_size(font, candidate)[0] <= max_width:
                return candidate
            trimmed = trimmed[:-1]
        return ''

    def init_display(self):
        self.epd.init()
        self.epd.Clear(0xFF)

    def close(self):
        self.epd.sleep()

    def updateTime(self):
        current = self._run('date +%H:%M')
        if current != self.saved_time:
            self.push_update = True
        self.saved_time = current

    def updateThermals(self):
        cpu_temps = []
        for zone in Path('/sys/class/thermal').glob('thermal_zone*'):
            try:
                zone_type = (zone / 'type').read_text().strip()
                if zone_type not in {'cpub_thermal_zone', 'cpul_thermal_zone'}:
                    continue
                temp_c = int((zone / 'temp').read_text().strip()) / 1000
                cpu_temps.append(temp_c)
            except Exception:
                pass

        if cpu_temps:
            temp_text = f'{max(cpu_temps):.0f}°C'
        else:
            temp_text = '--°C'

        pwm_percent = None
        for pwm_path in sorted(Path('/sys/class/hwmon').glob('hwmon*/pwm1')):
            try:
                pwm_value = int(pwm_path.read_text().strip())
                pwm_percent = round((pwm_value / 255) * 100)
                break
            except Exception:
                pass

        fan_text = f'{pwm_percent}%'
        if pwm_percent is None:
            fan_text = '--%'

        if temp_text != self.saved_temp or fan_text != self.saved_fan:
            self.push_update = True
        self.saved_temp = temp_text
        self.saved_fan = fan_text

    def updateSSID(self):
        ssid = self._run("""nmcli -t -f ACTIVE,SSID dev wifi | awk -F: '$1==\"yes\" {print $2; exit}'""")
        if not ssid:
            ssid = self._run("""nmcli -t -f GENERAL.CONNECTION device show wlan0 | awk -F': ' '$1==\"GENERAL.CONNECTION\" {print $2; exit}'""")
        if not ssid or ssid == '--':
            ssid = 'Connecting...'
        if ssid != self.saved_ssid:
            self.push_update = True
        self.saved_ssid = ssid

    def updateWiFiSignal(self):
        signal = self._run("""nmcli -t -f ACTIVE,SIGNAL dev wifi | awk -F: '$1==\"yes\" {print $2; exit}'""")
        signal_text = '--%'
        if signal:
            try:
                signal_value = int(signal)
                signal_value = max(0, min(100, int(round(signal_value / 5) * 5)))
                signal_text = f'{signal_value}%'
            except ValueError:
                pass
        if signal_text != self.saved_signal:
            self.push_update = True
        self.saved_signal = signal_text

    def updateIP(self):
        ip = self._run("nmcli -t -f IP4.ADDRESS device show wlan0 | cut -d: -f2- | head -n 1")
        if ip:
            ip = ip.split('/')[0]
        if not ip:
            ip = self._run("ip -4 -o addr show dev wlan0 | awk '{print $4}' | cut -d/ -f1 | head -n 1")
        tunnel_arrow = ''
        if TUNNEL_REMOTE:
            tunnel = self._run(f"ss -tn state established '( dst {TUNNEL_REMOTE} )' | tail -n +2")
            tunnel_arrow = '▲' if tunnel else '▼'
        display_ip = f'{tunnel_arrow} {ip}'.strip()
        if display_ip != self.saved_ip:
            self.push_update = True
        self.saved_ip = display_ip

    def getListenPorts(self):
        ports = self._run("ss -lntH | awk '$4 ~ /^0\\.0\\.0\\.0:/ {print $4}' | sed 's/.*://' | sort -n | uniq").splitlines()
        ports = [port for port in ports if port and port not in HIDDEN_PORTS]
        ports_string = ','.join(ports)
        if ports_string != self.ports:
            self.push_update = True
        self.ports = ports_string

    def updateSystemStats(self):
        uptime_text = '--'
        try:
            uptime_seconds = int(float(Path('/proc/uptime').read_text().split()[0]))
            days, rem = divmod(uptime_seconds, 86400)
            hours, rem = divmod(rem, 3600)
            minutes, _ = divmod(rem, 60)
            if days:
                uptime_text = f'{days}d {hours}h'
            elif hours:
                uptime_text = f'{hours}h {minutes}m'
            else:
                uptime_text = f'{minutes}m'
        except Exception:
            pass

        disk_text = '--'
        try:
            free_bytes = shutil.disk_usage('/').free
            free_gib = free_bytes / (1024 ** 3)
            if free_gib >= 10:
                disk_text = f'{free_gib:.0f}G'
            else:
                disk_text = f'{free_gib:.1f}G'
        except Exception:
            pass

        ram_text = '--'
        try:
            meminfo = {}
            for line in Path('/proc/meminfo').read_text().splitlines():
                key, value = line.split(':', 1)
                meminfo[key] = int(value.strip().split()[0])
            total_kib = meminfo.get('MemTotal', 0)
            available_kib = meminfo.get('MemAvailable', 0)
            used_kib = max(0, total_kib - available_kib)
            if total_kib > 0:
                ram_text = f'{(used_kib / total_kib) * 100:.0f}%'
        except Exception:
            pass

        if uptime_text != self.saved_uptime or disk_text != self.saved_disk or ram_text != self.saved_ram:
            self.push_update = True
        self.saved_uptime = uptime_text
        self.saved_disk = disk_text
        self.saved_ram = ram_text

    def updatePositions(self):
        face_left, face_top, face_right, face_bottom = self._text_bbox(self.font_face, self.saved_face)
        face_w = face_right - face_left
        face_h = face_bottom - face_top
        self.loc_center = (
            int((self.canvas_width - face_w) / 2) - face_left,
            int((self.canvas_height - face_h) / 2) - face_top - 2,
        )

        _, time_top, time_right, time_bottom = self._text_bbox(self.font_small, self.saved_time)
        _, stats_top, stats_right, stats_bottom = self._text_bbox(self.font_small, f'{self.saved_temp} {self.saved_fan}')
        _, uptime_top, _, uptime_bottom = self._text_bbox(self.font_small, self.saved_uptime)
        _, disk_top, disk_right, disk_bottom = self._text_bbox(self.font_small, self.saved_disk)
        _, ram_top, ram_right, ram_bottom = self._text_bbox(self.font_small, self.saved_ram)
        _, signal_top, _, signal_bottom = self._text_bbox(self.font_small, self.saved_signal)
        _, ports_top, ports_right, ports_bottom = self._text_bbox(self.font_small, self.ports)
        _, _, ip_right, ip_bottom = self._text_bbox(self.font_small, self.saved_ip)
        _, _, _, ssid_bottom = self._text_bbox(self.font_small, self.saved_ssid)

        top_gap = 7
        bottom_y = self.canvas_height - max(ip_bottom, ssid_bottom) - self.margin_y
        bottom_left_second_y = bottom_y - (signal_bottom - signal_top) - 2
        bottom_right_second_y = bottom_y - (ports_bottom - ports_top) - 2
        top_y = self.margin_y - time_top
        top_second_y = top_y + (time_bottom - time_top) + top_gap

        self.loc_top_left = (self.margin_x, top_y)
        self.loc_top_left_sub = (self.margin_x, top_second_y - uptime_top)
        self.loc_top_center = (int((self.canvas_width - time_right) / 2), top_y)
        self.loc_top_right = (self.canvas_width - stats_right - self.margin_x, top_y)
        self.loc_top_right_sub = (self.canvas_width - disk_right - self.margin_x, top_second_y - disk_top)
        self.loc_top_right_sub2 = (self.canvas_width - ram_right - self.margin_x, top_second_y + (disk_bottom - disk_top) + 3 - ram_top)
        self.loc_bot_left = (self.margin_x, bottom_y)
        self.loc_bot_left_sub = (self.margin_x, bottom_left_second_y - signal_top)
        self.loc_bot_right = (self.canvas_width - ip_right - self.margin_x, bottom_y)
        self.loc_bot_right_sub = (self.canvas_width - ports_right - self.margin_x, bottom_right_second_y - ports_top)

    def makeFace(self):
        self.saved_face = random.choice(self.faces)

    def build_image(self):
        image = Image.new('1', (self.canvas_width, self.canvas_height), 255)
        draw = ImageDraw.Draw(image)

        top_center_x = self.loc_top_center[0]
        bot_right_x = self.loc_bot_right[0]
        top_left_text = self._fit_text(self.name, self.font_small, max(0, top_center_x - self.margin_x * 2))
        top_left_sub_text = self._fit_text(self.saved_uptime, self.font_small, max(0, top_center_x - self.margin_x * 2))
        bot_left_signal = self._fit_text(self.saved_signal, self.font_small, max(0, bot_right_x - self.margin_x * 2))
        bot_left_text = self._fit_text(self.saved_ssid, self.font_small, max(0, bot_right_x - self.margin_x * 2))
        bot_right_ports = self._fit_text(self.ports, self.font_small, max(0, self.canvas_width - self.margin_x * 2))

        draw.text(self.loc_top_left, top_left_text, fill=0, font=self.font_small)
        draw.text(self.loc_top_left_sub, top_left_sub_text, fill=0, font=self.font_small)
        draw.text(self.loc_center, self.saved_face, fill=0, font=self.font_face)
        draw.text(self.loc_top_center, self.saved_time, fill=0, font=self.font_small)
        draw.text(self.loc_top_right, f'{self.saved_temp} {self.saved_fan}', fill=0, font=self.font_small)
        draw.text(self.loc_top_right_sub, self.saved_disk, fill=0, font=self.font_small)
        draw.text(self.loc_top_right_sub2, self.saved_ram, fill=0, font=self.font_small)
        draw.text(self.loc_bot_left_sub, bot_left_signal, fill=0, font=self.font_small)
        draw.text(self.loc_bot_left, bot_left_text, fill=0, font=self.font_small)
        draw.text(self.loc_bot_right_sub, bot_right_ports, fill=0, font=self.font_small)
        draw.text(self.loc_bot_right, self.saved_ip, fill=0, font=self.font_small)
        return image

    def write(self):
        image = self.build_image()
        buffer = self.epd.getbuffer(image)

        if not self.partial_ready:
            self.epd.displayPartBaseImage(buffer)
            self.partial_ready = True
            self.partial_updates = 0
            return

        if self.partial_updates >= self.full_refresh_every:
            self.epd.display(buffer)
            self.epd.displayPartBaseImage(buffer)
            self.partial_updates = 0
            return

        self.epd.displayPartial(buffer)
        self.partial_updates += 1


def main():
    parser = argparse.ArgumentParser()
    parser.add_argument('--interval', type=int, default=10)
    parser.add_argument('--once', action='store_true')
    args = parser.parse_args()

    screen = Screen()
    screen.init_display()

    try:
        while True:
            screen.updateTime()
            screen.updateSSID()
            screen.updateWiFiSignal()
            screen.updateIP()
            screen.updateThermals()
            screen.updateSystemStats()
            screen.getListenPorts()

            if screen.push_update:
                screen.makeFace()
                screen.updatePositions()
                screen.write()
                screen.push_update = False

            if args.once:
                break
            sleep(args.interval)
    finally:
        screen.close()


if __name__ == '__main__':
    main()

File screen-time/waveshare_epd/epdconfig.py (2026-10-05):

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

import os
import logging
import sys
import time
import subprocess

from ctypes import *

import gpiod
from gpiod.line import Bias, Direction, Value

logger = logging.getLogger(__name__)


class RaspberryPi:
    # Pin definition
    RST_PIN  = 17
    DC_PIN   = 25
    CS_PIN   = 8
    BUSY_PIN = 24
    PWR_PIN  = 18
    MOSI_PIN = 10
    SCLK_PIN = 11

    def __init__(self):
        import spidev
        import gpiozero
        
        self.SPI = spidev.SpiDev()
        self.GPIO_RST_PIN    = gpiozero.LED(self.RST_PIN)
        self.GPIO_DC_PIN     = gpiozero.LED(self.DC_PIN)
        # self.GPIO_CS_PIN     = gpiozero.LED(self.CS_PIN)
        self.GPIO_PWR_PIN    = gpiozero.LED(self.PWR_PIN)
        self.GPIO_BUSY_PIN   = gpiozero.Button(self.BUSY_PIN, pull_up = False)

        

    def digital_write(self, pin, value):
        if pin == self.RST_PIN:
            if value:
                self.GPIO_RST_PIN.on()
            else:
                self.GPIO_RST_PIN.off()
        elif pin == self.DC_PIN:
            if value:
                self.GPIO_DC_PIN.on()
            else:
                self.GPIO_DC_PIN.off()
        # elif pin == self.CS_PIN:
        #     if value:
        #         self.GPIO_CS_PIN.on()
        #     else:
        #         self.GPIO_CS_PIN.off()
        elif pin == self.PWR_PIN:
            if value:
                self.GPIO_PWR_PIN.on()
            else:
                self.GPIO_PWR_PIN.off()

    def digital_read(self, pin):
        if pin == self.BUSY_PIN:
            return self.GPIO_BUSY_PIN.value
        elif pin == self.RST_PIN:
            return self.RST_PIN.value
        elif pin == self.DC_PIN:
            return self.DC_PIN.value
        # elif pin == self.CS_PIN:
        #     return self.CS_PIN.value
        elif pin == self.PWR_PIN:
            return self.PWR_PIN.value

    def delay_ms(self, delaytime):
        time.sleep(delaytime / 1000.0)

    def spi_writebyte(self, data):
        self.SPI.xfer(list(data))

    def spi_writebyte2(self, data):
        for offset in range(0, len(data), 4096):
            self.SPI.xfer(list(data[offset:offset + 4096]))

    def DEV_SPI_write(self, data):
        self.DEV_SPI.DEV_SPI_SendData(data)

    def DEV_SPI_nwrite(self, data):
        self.DEV_SPI.DEV_SPI_SendnData(data)

    def DEV_SPI_read(self):
        return self.DEV_SPI.DEV_SPI_ReadData()

    def module_init(self, cleanup=False):
        self.GPIO_PWR_PIN.on()
        
        if cleanup:
            find_dirs = [
                os.path.dirname(os.path.realpath(__file__)),
                '/usr/local/lib',
                '/usr/lib',
            ]
            self.DEV_SPI = None
            for find_dir in find_dirs:
                val = int(os.popen('getconf LONG_BIT').read())
                logging.debug("System is %d bit"%val)
                if val == 64:
                    so_filename = os.path.join(find_dir, 'DEV_Config_64.so')
                else:
                    so_filename = os.path.join(find_dir, 'DEV_Config_32.so')
                if os.path.exists(so_filename):
                    self.DEV_SPI = CDLL(so_filename)
                    break
            if self.DEV_SPI is None:
                RuntimeError('Cannot find DEV_Config.so')

            self.DEV_SPI.DEV_Module_Init()

        else:
            # SPI device, bus = 0, device = 0
            self.SPI.open(0, 0)
            self.SPI.max_speed_hz = 4000000
            self.SPI.mode = 0b00
        return 0

    def module_exit(self, cleanup=False):
        logger.debug("spi end")
        self.SPI.close()

        self.GPIO_RST_PIN.off()
        self.GPIO_DC_PIN.off()
        self.GPIO_PWR_PIN.off()
        logger.debug("close 5V, Module enters 0 power consumption ...")
        
        if cleanup:
            self.GPIO_RST_PIN.close()
            self.GPIO_DC_PIN.close()
            # self.GPIO_CS_PIN.close()
            self.GPIO_PWR_PIN.close()
            self.GPIO_BUSY_PIN.close()
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

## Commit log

2026-10-05 Fix Cubie A7Z e-paper GPIO-bank power after kernel upgrade
    [epd_test.py, epdconfig.py, gpio_probe.py]
2026-10-05 fix(fan): restore PWM fan overlay and dynamic hwmon discovery
